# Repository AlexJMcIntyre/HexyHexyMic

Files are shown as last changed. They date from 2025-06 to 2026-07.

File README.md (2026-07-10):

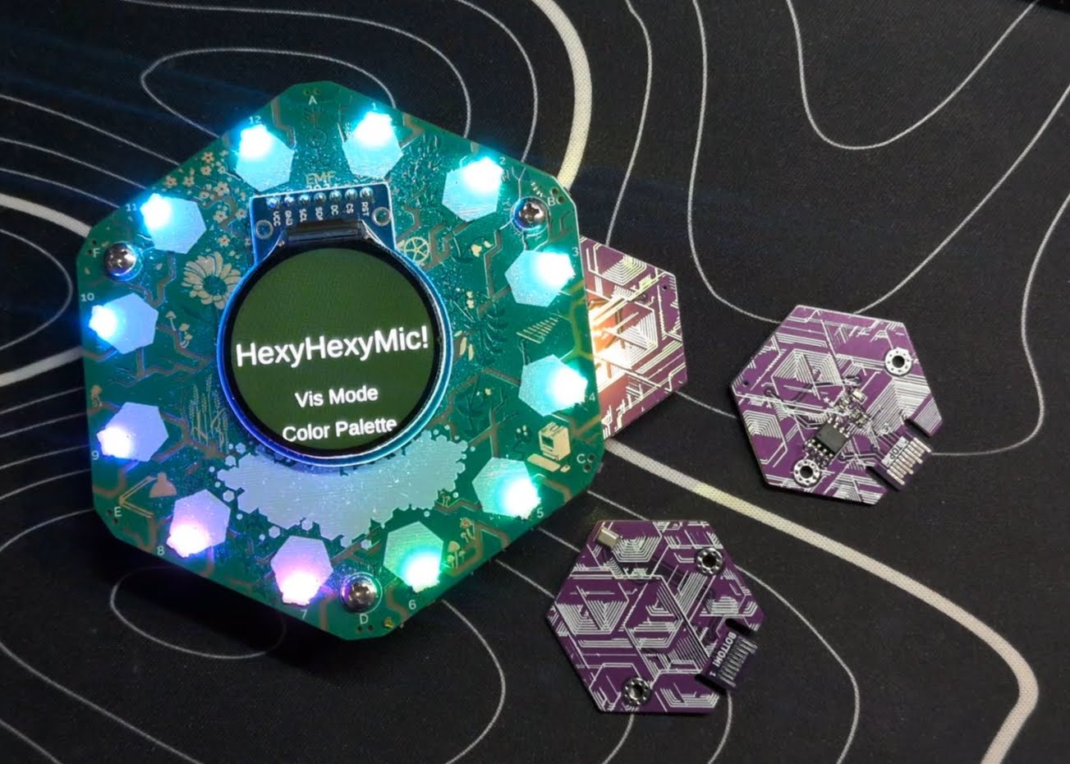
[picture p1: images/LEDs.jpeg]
HexyHexyMic in action


# HexyHexyMic

Because EMF needed more flashy lights!

If you're here, there's a good chance you've picked up one of my **HexyHexyMic** Hexpansions. I hope I got the chance to say hello! If not, you can find me on Mastodon: **@GlitchEngine@mastodon.social**.

HexyHexyMic adds a digital microphone to the Tildagon badge, along with a collection of audio-reactive visualisations for the badge LEDs.

This was my first attempt at building a Tildagon Hexpansion, and also my first serious dive into audio signal processing. 

The entire application is written in MicroPython and is baked into the EEPROM on the Hexpansion.

If you enjoyed this project or picked up a HexyMic at EMF2026, donations towards parts and future projects are appreciated, but never expected:

https://ko-fi.com/AlexJMcIntyre

https://paypal.me/AlexJMcIntyre

----------

## Usage

The app lives on the Hexpansion itself, so there are **no downloads or internet connection required**.

Simply plug the Hexpansion into your badge and it should launch automatically. If the badge is powered on with the Hexpansion already connected, it should load immediately during startup.

To exit the app gracefully, press the **F** button (top left).

Removing the Hexpansion should also exit automatically. If your LEDs don't return afterwards, try toggling them back on from the badge menu or simply reboop the badge.

### Controls

-   **Up / Down**: Navigate the menu
-   **C** (bottom right): Select an option
-   **F** (top left): Exit the application

----------

## Visualisation Modes

### RMS (default)

Uses the **Root Mean Square** of the incoming audio as a measure of volume.

The louder the sound, the more LEDs illuminate.

### Zero Crossing (ZC)

Counts how often the audio waveform crosses zero to estimate its average pitch.

It's a very lightweight algorithm that gives surprisingly fun results despite being only a rough approximation.

### FFT

Performs a tiny **Fast Fourier Transform** to estimate the energy in twelve frequency bands.

This isn't intended to be an accurate spectrum analyser, but it's fast enough to run smoothly on the badge and gives a satisfying visual representation of the music.

### Vortex

Attempts to detect the beat of whatever it's listening to and synchronise a rotating comet of light with the rhythm.

It's definitely more artistic than scientific, but I think it looks rather nice.

----------

## Beat Flash

When enabled, the app attempts to detect musical beats from the incoming audio. Whenever it thinks it has found one, the LEDs briefly desaturate to create a bright flash effect.

Beat detection is intentionally simple, so don't expect perfect DJ-grade synchronisation. It works best with music that has a clear, steady rhythm.

----------

## Automatic Volume Calibration

The visualisers automatically adapt to the ambient sound level.

This means they work just as well in a quiet workshop as they do in a noisy concert.

If you make an unusually loud noise (for example by tapping the microphone), the display may become less sensitive for a few seconds while it recalibrates itself.

----------

## Compatibility

Tested with **Tildagon firmware 1.10**.

----------

## Hacking on HexyHexyMic

The source is included in this repository, but unlike a normal Python application it isn't installed directly onto the badge.

The app is flashed onto the Hexpansion's EEPROM, allowing it to run automatically whenever the Hexpansion is plugged into a Tildagon.

To build or modify the app you'll currently need:

- A checkout of the Tildagon firmware repository
- This project's source files
- A way of flashing the EEPROM on the Hexpansion

I've included the batch files I use to build and flash the EEPROM image as a starting point. They're fairly simple, but you'll need to adjust the paths for your own setup.

If you improve the code or add new visualisation modes, I'd love to hear about it!

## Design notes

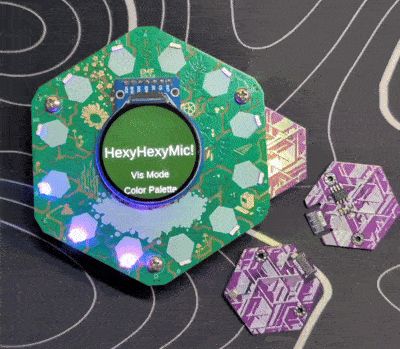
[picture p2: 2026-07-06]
images/LEDs.gif

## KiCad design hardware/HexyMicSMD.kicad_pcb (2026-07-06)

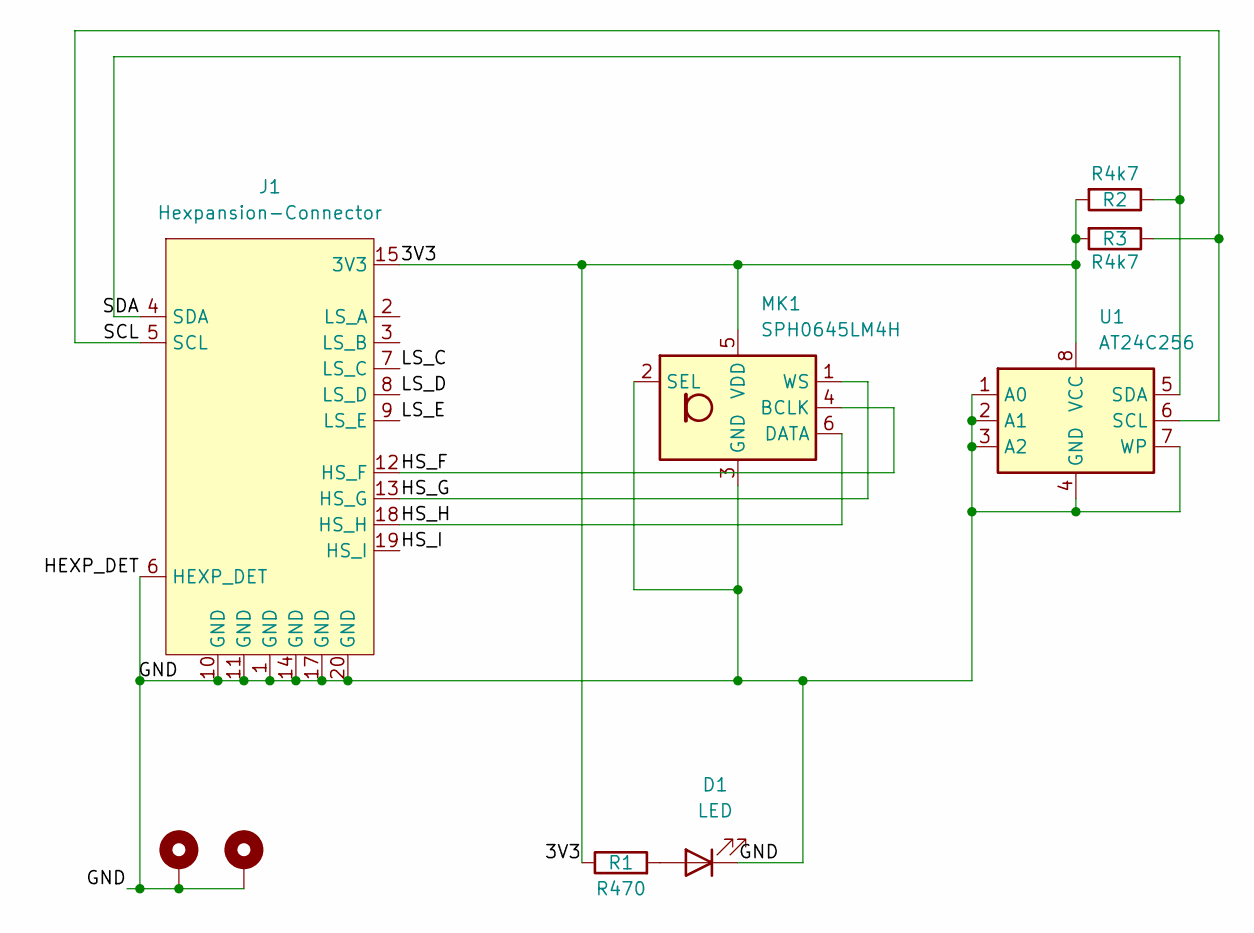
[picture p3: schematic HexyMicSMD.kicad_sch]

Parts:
D1: LED; LED_0603_1608Metric; LCSC C2286
H1: MountingHole_Pad; MountingHole_2.2mm_M2_Pad_Via; LCSC 0
H2: MountingHole_Pad; MountingHole_2.2mm_M2_Pad_Via
J1: Hexpansion-Connector; hexpansion-edge-connector
MK1: SPH0645LM4H; Knowles_SPH0645LM4H-6_3.5x2.65mm; LCSC C19272537
R1: R470; R_0603_1608Metric; LCSC C23179
R2, R3: R4k7; R_0603_1608Metric; LCSC C21190
U1: AT24C256; SOIC-8_3.9x4.9mm_P1.27mm; LCSC C19723712

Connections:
/3V3: J1.15 (3V3), J1.16 (3V3), MK1.5 (VDD), R1.1, R2.2, R3.2, U1.8 (VCC)
/GND: D1.1 (K), H1.1, H2.1, J1.1 (GND), J1.6 (HEXP_DET), J1.10 (GND), J1.11 (GND), J1.14 (GND), J1.17 (GND), J1.20 (GND), MK1.2 (SEL), MK1.3 (GND), U1.1 (A0), U1.2 (A1), U1.3 (A2), U1.4 (GND), U1.7 (WP)
/HS_F: J1.12 (HS_F), MK1.4 (BCLK)
/HS_G: J1.13 (HS_G), MK1.1 (WS)
/HS_H: J1.18 (HS_H), MK1.6 (DATA)
/HS_I: J1.19 (HS_I)
/LS_C: J1.7 (LS_C)
/LS_D: J1.8 (LS_D)
/LS_E: J1.9 (LS_E)
/SCL: J1.5 (SCL), R3.1, U1.6 (SCL)
/SDA: J1.4 (SDA), R2.1, U1.5 (SDA)
unnamed: D1.2 (A), R1.2

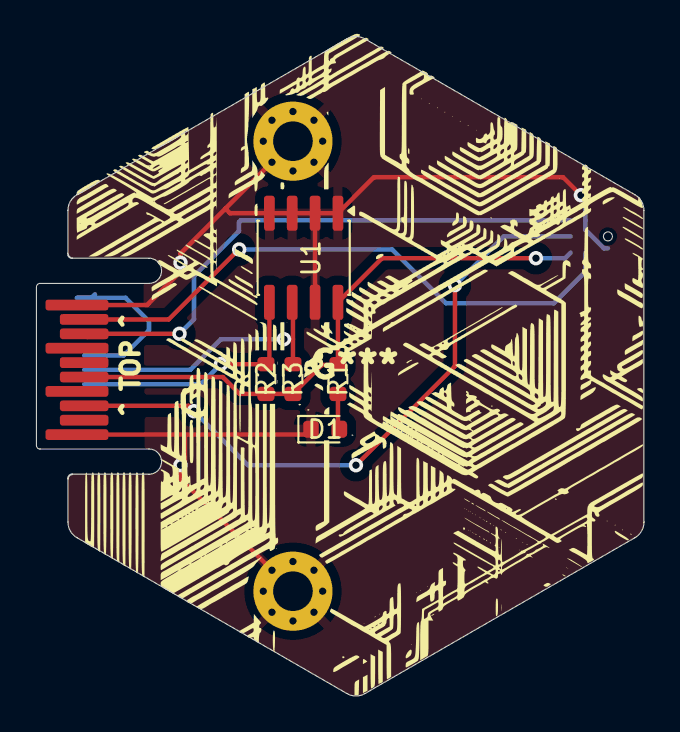
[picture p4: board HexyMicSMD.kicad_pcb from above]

Board: 2 copper layers, 33.7 x 36.6 mm, 9 parts (1 on the bottom side), 8 nets.

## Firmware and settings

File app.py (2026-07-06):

import app
import struct
import math
import time
from machine import Pin, I2S, I2C
from app_components import clear_background, Menu, Notification
from system.eventbus import eventbus
from system.patterndisplay.events import PatternDisable, PatternEnable
from system.scheduler.events import RequestForegroundPushEvent
from tildagonos import tildagonos

def hsv_to_rgb(h, s, v):
    h_i = int(h * 6)
    f = h * 6 - h_i
    p = int(255 * v * (1 - s))
    q = int(255 * v * (1 - f * s))
    t = int(255 * v * (1 - (1 - f) * s))
    v = int(255 * v)
    h_i = h_i % 6
    if h_i == 0:
        return v, t, p
    elif h_i == 1:
        return q, v, p
    elif h_i == 2:
        return p, v, t
    elif h_i == 3:
        return p, q, v
    elif h_i == 4:
        return t, p, v
    else:
        return v, p, q
    
menu_items = [
    "HexyHexyMic!",
    "Vis Mode",
    "Color Palette",
    "Beat Flash",
    "Brightness"
]

class MicApp(app.App):
    def __init__(self, config=None):
        eventbus.emit(PatternDisable()) # disable the ambient pattern. We're going to need those LEDs!
        self.hexpansion_config = config
        self.foregrounded = False

        self.buffersize = 1024 * 4 # this seems baked into the esp32, can't go lower. 

        self.rms = 0.0 # current rms volume
        self.rmin = 1.0 # rolling minimum
        self.rmax = 10.0 # rolling maximum
        self.relative = 0.1 # relative volume
        self.window_decay = 0.99 # how quickly the rolling min and max adjust to changes in volume. Closer to 1 is slower decay, closer to 0 is faster decay
        
        self.brightness_control = 0.5 # global brightness modifier
        self.led_high_levels = [0.0] * 12  # High water mark for each led
        self.led_high_decay = 0.3 # high water mark decay

        self.buffer = bytearray(self.buffersize) #buffer to get the raw bitstream from the mic

        # set up the microphone
        self.i2s = I2S(
            0,
            sck=self.hexpansion_config.pin[0],
            ws=self.hexpansion_config.pin[1],
            sd=self.hexpansion_config.pin[2],
            mode=I2S.RX,
            bits=32,
            format=I2S.MONO,
            rate=48000,
            ibuf=self.buffersize
        )
    
        #set up the menu        
        self.vismode = 0
        self.vismodes = ["RMS", "ZC", "FFT", "Vortex"]
        self.palette = 0   
        self.palettes = [("Neon",(0.78,0.49,0.33)),
                        ("Ember",(0.02, 0.05, 0.09, 0.14)),
                        ("Deep",(0.70, 0.63, 0.56, 0.50)),
                        ("Flora",(0.42, 0.22, 0.15, 1.00)),
                        ("Berry", (0.95,0.88, 0.82, 0.6)),
                        ("Rainbow", (0.0, 0.08, 0.16, 0.33, 0.66, 0.81)),
                        ("Aurora", (0.27, 0.38, 0.49, 0.62))
                        ]
        
        self.menu = Menu(
            self,
            menu_items,
            select_handler=self.select_handler,
            back_handler=self.back_handler,
        )
        self.notification = None

        # FFT prep
        self.num_bins = 12
        self.sample_count = 64 # Keep this small for speed!
        self.bin_maxes = [1.0] * 12

        self.angle = 0

        # Precompute Sin/Cos tables for the frequencies we care about
        self.sin_table = [math.sin(2 * math.pi * i / self.sample_count) for i in range(self.sample_count)]
        self.cos_table = [math.cos(2 * math.pi * i / self.sample_count) for i in range(self.sample_count)]

        #beat detection prep
        self.energy_history = [0.0] * 60 # Roughly 1-2 seconds of history
        self.last_beat_time = 0
        self.min_beat_interval = 200 # Minimum 300ms between beats (max ~200 BPM)
        self.last_beat_ms = time.ticks_ms()
        self.beat_interval = 500  # Start with a 120 BPM guess
        self.target_index = 6.0   # Adjust this (0-11) to define "bottom
        self.beat = False
        self.beat_flash = False
        
        #end init
    
    def get_hue(self, distance):
        live_palette = self.palettes[self.palette][1]
        num_segments = len(live_palette) - 1

        # Ensure distance doesn't exceed 1.0
        distance = max(0, min(0.999, distance))

        scaled_dist = distance * num_segments
        index = int(math.floor(scaled_dist))  # The starting color index
        fraction = scaled_dist - index
        start_hue = live_palette[index]
        end_hue = live_palette[index + 1]
        # Simple LERP formula: start + (end - start) * fraction
        return start_hue + (end_hue - start_hue) * fraction
    
    def sample_audio(self, subsample = 1):
        num_bytes_read = self.i2s.readinto(self.buffer) # get the raw bitstream 
        if num_bytes_read <= 0: return

        samples = []
        for i in range(0, num_bytes_read, subsample * 4): # subsampling allows to to cut the number of samples
            val = struct.unpack('<i', self.buffer[i:i+4])[0] #4 bytes gives us our 32 bit word 
            samples.append(val >> 8) #bitshift since our 32 bit word only contains 24 bits of data 
        return samples
     
    def audio_RMS(self):
        samples = self.sample_audio(1)
        # 2. Find the DC offset of THIS specific block
        block_avg = sum(samples) / len(samples)

        sum_squares = 0
        for s in samples:
            centered = s - block_avg
            sum_squares += centered * centered

        self.rms = math.sqrt(sum_squares / len(samples))
        if self.rms < self.rmin:
            self.rmin = self.rms
        else:
            self.rmin = self.rmin / self.window_decay
        if self.rms > self.rmax:
            self.rmax = self.rms
        else:
            self.rmax = self.rmax * self.window_decay

        # Get relative position
        self.relative = (self.rms - self.rmin) / (self.rmax - self.rmin) if (self.rmax - self.rmin) > 0 else 0
        self.relative = self.relative**2

        total_brightness = 12.0 * self.relative
        led_brightness = [0.0] * 12
        for i in range(12):
            if total_brightness >= 1:
                led_brightness[i] = 1
                total_brightness-=1
            else:
                led_brightness[i] = total_brightness
                total_brightness = 0
        #pass the led brightness to the linear led function:
        self.paint_leds_linear(led_brightness, 6)
        
    def audio_ZC(self):
        samples = self.sample_audio(4)

        avg = sum(samples) / len(samples)
        
        # Pass 2: Metrics
        sum_abs_diff = 0
        crossings = 0
        prev_sample = samples[0] - avg
        
        for s in samples:
            current_sample = s - avg
            sum_abs_diff += abs(current_sample)
            if (current_sample > 0 and prev_sample <= 0) or (current_sample < 0 and prev_sample >= 0):
                crossings += 1
            prev_sample = current_sample
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

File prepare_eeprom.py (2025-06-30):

from machine import I2C
from system.hexpansion.header import HexpansionHeader, write_header
from system.hexpansion.util import (
    detect_eeprom_addr,
    get_hexpansion_block_devices,
    read_hexpansion_header,
)
import vfs

# Need to init this to make sure i2c works

# Set up i2c
port = 2  # <<-- Customize!!
i2c = I2C(port)

# autodetect eeprom address
addr, addr_len = detect_eeprom_addr(i2c)
print("Detected eeprom at ")
print({hex(addr)})

# Fill in your desired header info here:
# use this one for the M24C16:
header_m24c16 = HexpansionHeader(
    manifest_version="2024",
    fs_offset=32,
    eeprom_page_size=16,
    eeprom_total_size=1024 * (16 // 8),
    vid=0xCA75,
    pid=0x1337,
    unique_id=0,
    friendly_name="M24C16",
)
# use this template for the ZD24C64A
header_zd24c64 = HexpansionHeader(
    manifest_version="2024",
    fs_offset=32,
    eeprom_page_size=32,
    eeprom_total_size=1024 * (64 // 8),
    vid=0xCA75,
    pid=0x1337,
    unique_id=0x0,
    friendly_name="ZD24C64A",
)

header_cat24c512 = HexpansionHeader(
    manifest_version="2024",
    fs_offset=128,
    eeprom_page_size=128,
    eeprom_total_size=1024 * (512 // 8),
    vid=0xCA75,
    pid=0x1337,
    unique_id=0x0,
    friendly_name="CAT24C512",
)

header_at24c256 = HexpansionHeader(
    manifest_version="2024",
    fs_offset=64, 
    eeprom_page_size=64,
    eeprom_total_size=1024 * (256 // 8),  # = 32 KB
    vid=0xcafe,  
    pid=0x7A1D,  
    unique_id=0x0,
    friendly_name="HexHexMic",
)

# pick which one to use here
header = header_at24c256


# Write and read back header
write_header(
    port, header, addr=addr, addr_len=addr_len, page_size=header.eeprom_page_size
)
header = read_hexpansion_header(i2c, addr, set_read_addr=True, addr_len=addr_len)

if header is None:
    raise RuntimeError("Failed to read back hexpansion header")

# Get block devices
eep, partition = get_hexpansion_block_devices(i2c, header, addr, addr_len=addr_len)

# Format
vfs.VfsLfs2.mkfs(partition)

# And mount!
vfs.mount(partition, "/eeprom")

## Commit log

2025-06-24 Create v0_2.py, LED proof of concept
2026-07-06 Added Kicad project files and gerbers
    [HexyMicSMD-B_Cu.gbl, HexyMicSMD-B_Mask.gbs, HexyMicSMD-B_Paste.gbp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]
